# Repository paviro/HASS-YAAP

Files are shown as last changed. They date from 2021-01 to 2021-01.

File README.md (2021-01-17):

# HASS-YAAP
##### Yet another alarm (control) panel for Home Assistant.
* Change alarm system mode (away, home, night, disarmed)
* Welcome people arriving by their name
* Turn off all lights (when you leave for example)

### Usage

##### Arming & Disarming

1. Press `*` to enter code mode
2. Enter Pin
3. Finish sequence by using
   * `A`: Arm Away
   * `B`: Arm Night
   * `C`: Arm Home
   * `D`: Disarm
4. You can also reset the entered code by pressing `*` again

##### Turn of lights

Press `#` while on the main state screen. On any other screen `#` will go back to the main screen.

##### Enable LCD backlight

Press any key.

### Example Screens

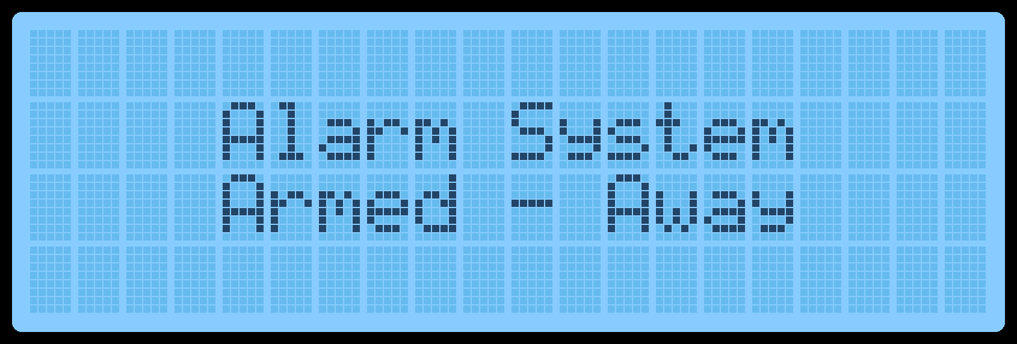
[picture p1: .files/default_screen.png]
Default Screen


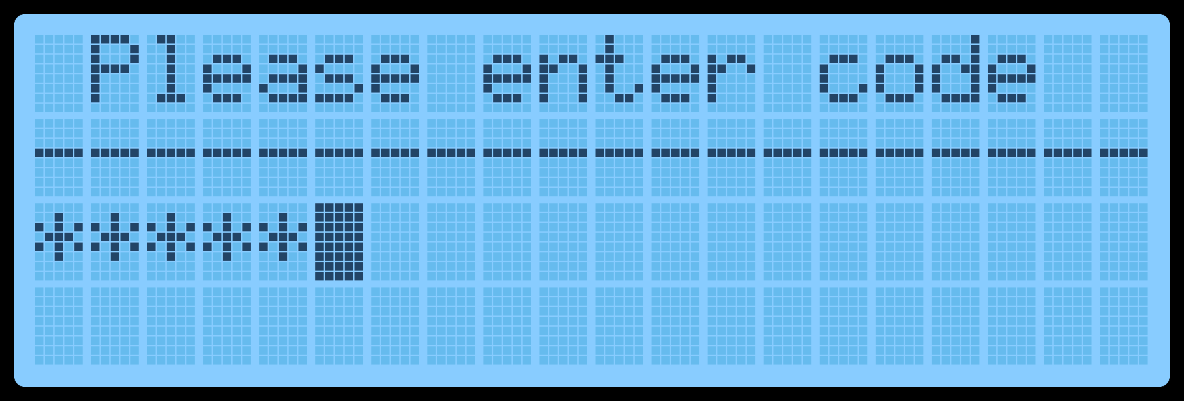
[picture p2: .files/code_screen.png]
Code


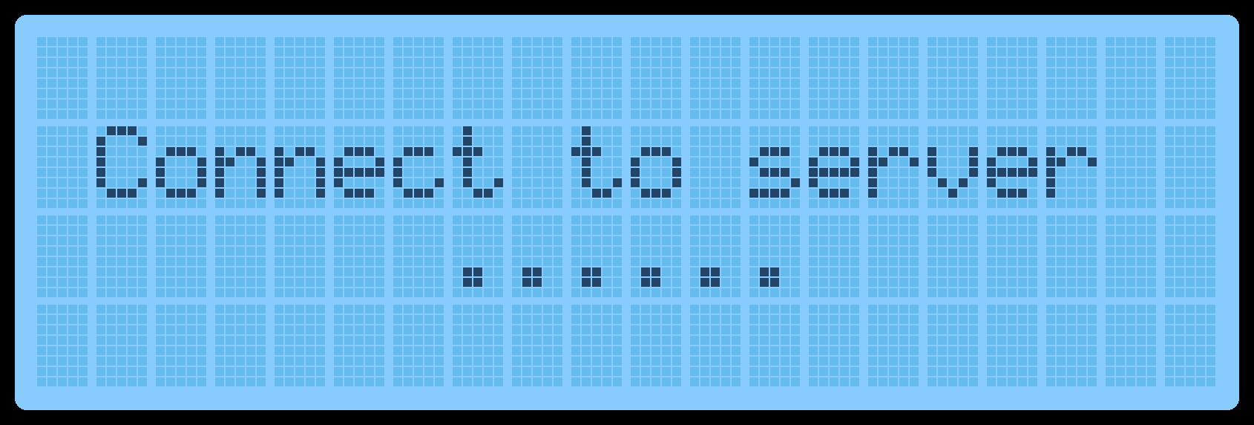
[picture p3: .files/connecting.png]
Connecting


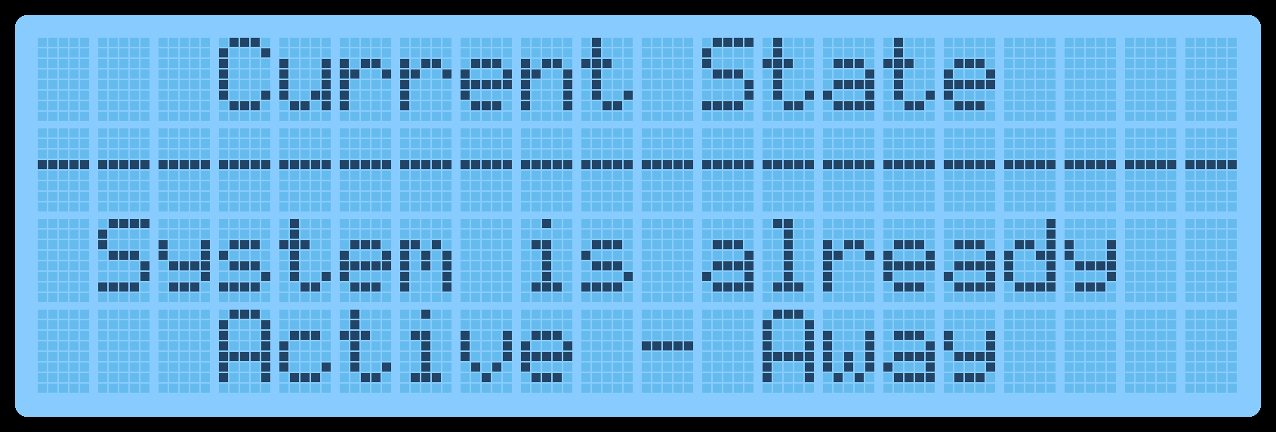
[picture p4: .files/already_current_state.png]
Current State


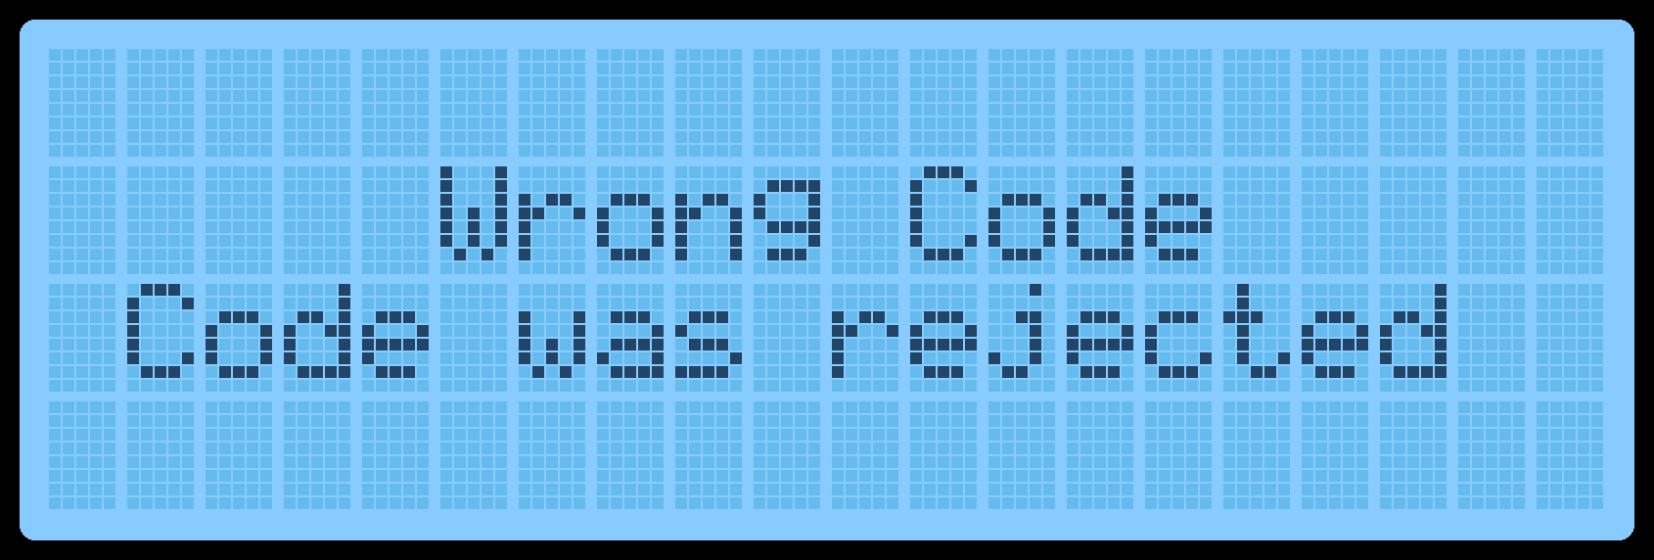
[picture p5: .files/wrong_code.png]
Wrong Code


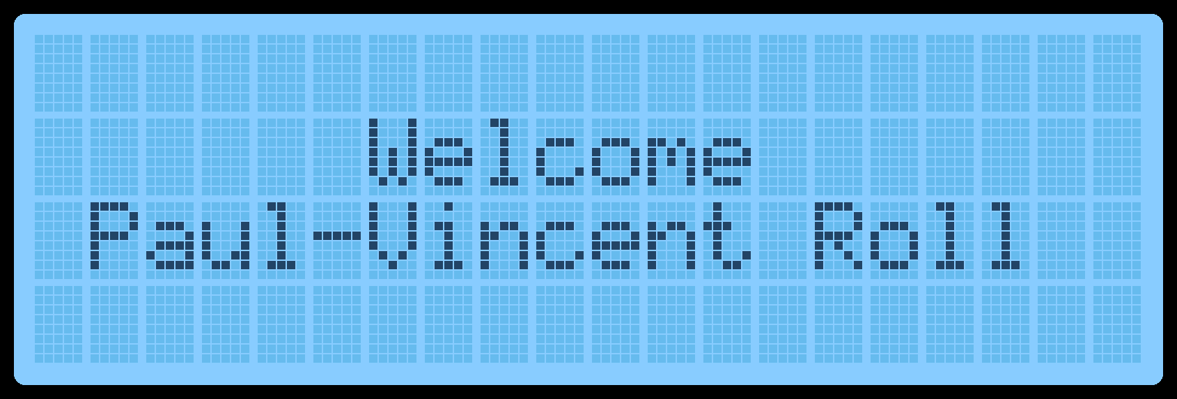
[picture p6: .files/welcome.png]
Welcome


## Used Hardware

#### Parts

* [4x4 Matrix Keypad Keyboard](https://www.az-delivery.de/en/products/4x4-matrix-numpad) 

* [4x20 characters LCD with I2C interface](https://www.az-delivery.de/en/products/hd44780-2004-lcd-display-bundle-4x20-zeichen-mit-i2c-schnittstelle)

* [ESP8266 Board](https://www.az-delivery.de/en/products/nodemcu-lua-amica-v2-modul-mit-esp8266-12e-unverloetet) (You will proably need to change the config in PlatformIO for your board)

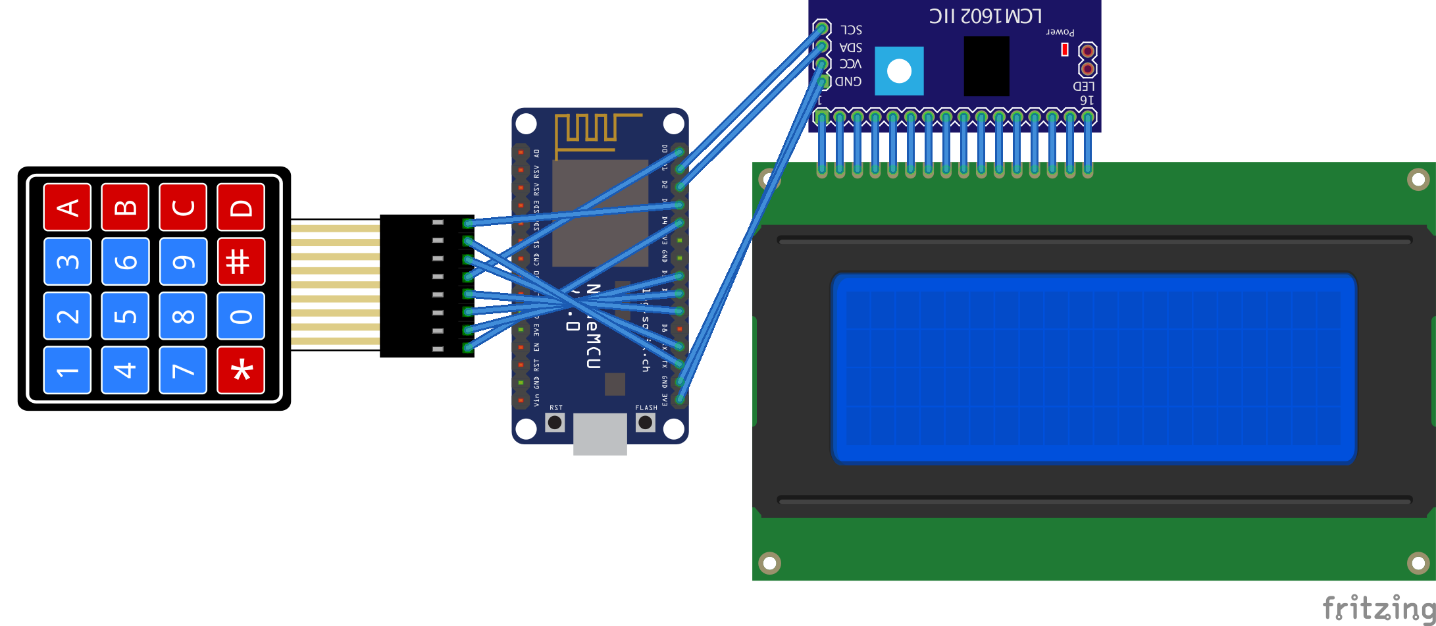
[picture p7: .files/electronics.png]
Electronics
You should probably choose a better pin layout than I did but apparently this is what I used judging from the code 😅

## ESP8266 Configuration

Download and install the [PlatformIO IDE](https://platformio.org).

Create a file called `config.h` in the folder `include` with the contents of [config_example.h](https://github.com/paviro/HASS-YAAP/blob/main/include/config_example.h).

Choose a language file (default selected is English):

```c++
#include "translations/EN.h"
```

Add your WiFi and MQTT credentials:

```c++
#define WiFi_SSID              "WiFi_SSID"
#define WiFi_PW                "WiFi_PW"
#define MQTT_SERVER_IP         "192.168.x.y"
#define MQTT_USER              "MQTT_USER"
#define MQTT_PW                "MQTT_PW"
#define MQTT_CLIENT_NAME       "AlarmControlPanel"
```

**Adjust the other settings to your liking.**

If needed adjust the settings in PlatformIO for your board.

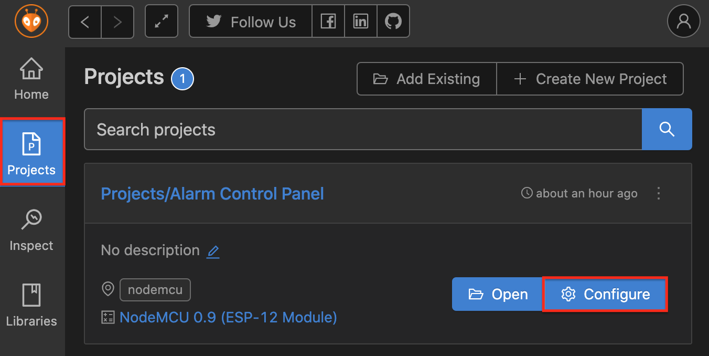
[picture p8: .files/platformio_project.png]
PlatformIO Project


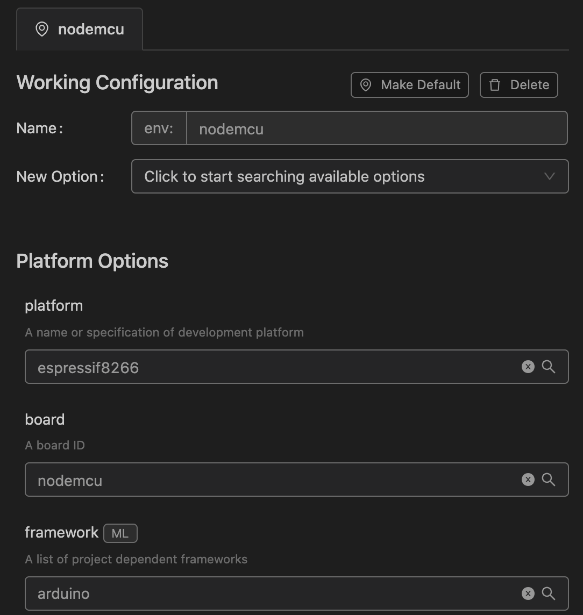
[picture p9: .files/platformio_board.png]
PlatformIO Project


## Home Assistant Configuration

### Requirements

* MQTT Server (for Home Assistant OS: [Mosquitto](https://github.com/home-assistant/addons/tree/master/mosquitto))

* An alarm system (for example: [Manual](https://www.home-assistant.io/integrations/manual/))

* Some Automations (see YAML below)

### MQTT

Setup a MQTT server, configure it in Home Assistant and add an account for the alarm panel on the server.

### Automations

#### Required automations

##### MQTT Alarm Panel - Alarm State

Sends alarm system changes to the panel & receives state requests from the panel.

Replace ```alarm_control_panel.alarmsystem```  with the entity id of your alarm system.

```yaml
- alias: "MQTT Alarm Panel - Alarm State"
  trigger:
    - platform: mqtt
      topic: "alarmpanel/get"
      payload: "state"
    - platform: state
      entity_id: alarm_control_panel.alarmsystem
  action:
    - service: mqtt.publish
      data:
        topic: "alarmpanel/state"
        payload: "{{ states('alarm_control_panel.alarmsystem') }}"
```

##### MQTT Alarm Panel - Alarm State

Automation to change the state of the alarm system. You can define valid codes in the ```variables``` section. 

The name of the code will be used to send a message to a specified phone when the alarm is disabled via the panel. You can disable this by removing the ```notify``` action.

Replace ```alarm_control_panel.alarmsystem```  with the entity id of your alarm system.

Replace ```notify.enter_phone_id_here```  with the entity id of your phone.

```yaml
- alias: "MQTT Alarm Panel - Set Alarm State"
  variables:
    codes:
      23342: "Code 1"
      6563434: "Code 2"
      9189938992: "Code 3"
  trigger:
    - platform: mqtt
      topic: "alarmpanel/arm/away"
    - platform: mqtt
      topic: "alarmpanel/arm/home"
    - platform: mqtt
      topic: "alarmpanel/arm/night"
    - platform: mqtt
      topic: "alarmpanel/disarm"
  action:
    - choose:
        - conditions:
            - condition: template
              value_template: '{{ trigger.payload | int in codes }}'
          sequence:
            - choose:
                - conditions:
                    - condition: template
                      value_template: "{{ trigger.topic == 'alarmpanel/arm/away' }}"
                  sequence:
                    - service: alarm_control_panel.alarm_arm_away
                      entity_id: alarm_control_panel.alarmsystem
                - conditions:
                    - condition: template
                      value_template: "{{ trigger.topic == 'alarmpanel/arm/home' }}"
                  sequence:
                    - service: alarm_control_panel.alarm_arm_home
                      entity_id: alarm_control_panel.alarmsystem
                - conditions:
                    - condition: template
                      value_template: "{{ trigger.topic == 'alarmpanel/arm/night' }}"
                  sequence:
                    - service: alarm_control_panel.alarm_arm_night
                      entity_id: alarm_control_panel.alarmsystem
                - conditions:
                    - condition: template
                      value_template: "{{ trigger.topic == 'alarmpanel/disarm' }}"
                  sequence:
                    - service: alarm_control_panel.alarm_disarm
                      entity_id: alarm_control_panel.alarmsystem
                    - service: notify.enter_phone_id_here
                      data_template:
                        message: >
                          Alarm system disarmed with code: {{codes[trigger.payload  | int]}}
                        title: "⚠️ Warning Alarmpanel"
      default:
        - service: mqtt.publish
          data:
            topic: "alarmpanel/arm/error"
            payload: "invalidCode"
        - service: notify.enter_phone_id_here
          data_template:
            message: >
               A wrong code was entered into the alarm panel: {{trigger.payload}}
            title: "⚠️ Warning Alarmpanel"
```

##### MQTT Alarm Panel - Lights off

Turns of your lights when ```#``` is pressed on the panel while on the alarm state screen.

```yaml
- alias: "MQTT Alarm Panel - Lights off"
  trigger:
    - platform: mqtt
      topic: "alarmpanel/lights"
      payload: "off"
  action:
    - service: light.turn_off
      entity_id: all
    - service: mqtt.publish
      data:
        topic: "alarmpanel/lights/callback"
        payload: "success"
```

#### Optional automations

##### Welcome Notification

The automation below will send the name of people arriving at your home to the alarm panel to display. 

If you have a motion / door sensor in the area it will wait for someone to be present near the panel. Remove the first action if you don't have one.

```yaml
- alias: "Welcome Notification"
  trigger:
    platform: event
    event_type: state_changed
  mode: parallel
  condition:
    condition: and
    conditions:
      - condition: template
        value_template: "{{ trigger.event.data.new_state is defined }}"
      - condition: template
        value_template: "{{ trigger.event.data.old_state is defined }}"
      - condition: template
        value_template: "{{ trigger.event.data.new_state.domain == 'person' }}"
      - condition: template
        value_template: "{{ trigger.event.data.new_state.state == 'home' }}"
      - condition: template
        value_template: "{{ trigger.event.data.old_state.state != 'home' }}"
  action:
    - wait_template: "{{ is_state('binary_sensor.motion_sensor_near_panel', 'on') }}"
      timeout: 300
      continue_on_timeout: false
    - service: mqtt.publish
      data:
        topic: "person/arrived"
        payload: "{{state_attr(trigger.event.data.entity_id, 'friendly_name')}}"
```

##### Motion Sensor

Turn on the LCD backlight if a motion sensor near the panel is triggered.

```yaml
- alias: "MQTT Alarm Panel - Turn LCD on when motion is detected"
  trigger:
    platform: state
    entity_id: binary_sensor.motion_sensor_near_panel
    to: 'on'
  action:
    - service: mqtt.publish
      data:
        topic: "alarmpanel/lcd"
        payload: "on"
```

## Roadmap

* TLS Support (Anyone want to give it a shot?)
* Support more display types?
* More translations

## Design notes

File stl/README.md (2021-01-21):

# Case files

In this folder you can find the STL files for the case. They were designed by Clemens Szelies.

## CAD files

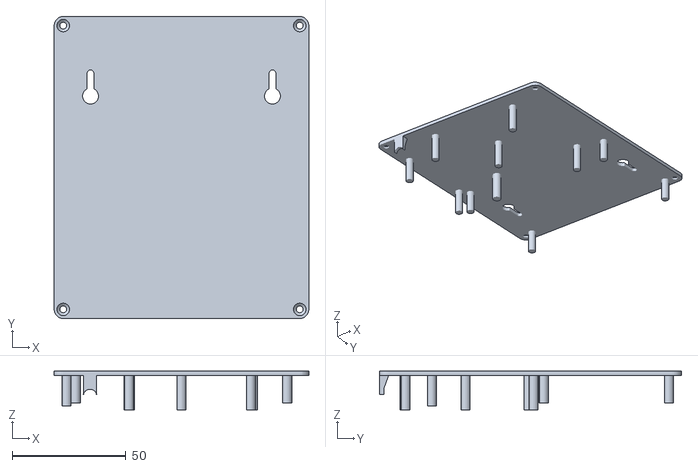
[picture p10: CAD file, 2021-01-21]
stl/Alarm-Panel Back x1.stl
112.0 x 132.8 x 17.1

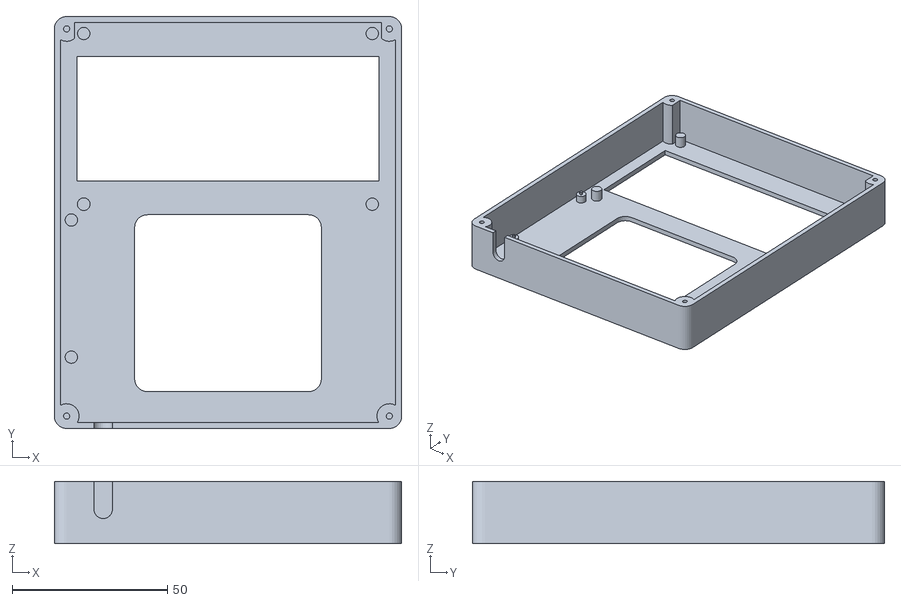
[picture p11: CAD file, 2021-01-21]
stl/Alarm-Panel Front x1.stl
112.0 x 132.8 x 20.1

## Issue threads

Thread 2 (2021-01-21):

Case files

lubbertkramer, 2021-01-21:
Did you print the case yourself or did you also buy this? If you have printed it where can i find the files ?

Thanks!

paviro, 2021-01-21:
The case was designed by a friend of mine. He is still finishing up some things as soon as he is done I’ll add it to the repo.

lubbertkramer, 2021-01-21:
Great to hear! But is it possible to also share the case you have used/printed?

paviro, 2021-01-21:
Mhh? As I said it’s still being finished up. I had to improvise some things on the particular one I printed.

paviro, 2021-01-21:
Files added at https://github.com/paviro/HASS-YAAP/tree/main/stl

Closed 2021-01-21.

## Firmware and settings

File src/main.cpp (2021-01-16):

#include <Arduino.h>
#include <EspMQTTClient.h>
#include <Dictionary.h>
#include <Keypad.h>
#include <Wire.h>
#include <LiquidCrystal_I2C.h>
#include <screen.h>
#include <config.h>

// general
String currentAlarmState;
String code;

// Dictionaries
Dictionary & internalStates = * (new Dictionary(6));
Dictionary & strings = * (new Dictionary(6));

EspMQTTClient client(WiFi_SSID,WiFi_PW,MQTT_SERVER_IP,MQTT_USER,MQTT_PW,MQTT_CLIENT_NAME);

byte keypadRowPins[KEYPAD_ROWS] = {KEYPAD_ROW_PINS};
byte keypadColPins[KEYPAD_COLS] = {KEYPAD_COL_PINS};
Keypad customKeypad = Keypad(makeKeymap(keypadMap), keypadRowPins, keypadColPins, KEYPAD_ROWS, KEYPAD_COLS);

LiquidCrystal_I2C lcd(SCREEN_ADDRESS, SCREEN_WIDTH, SCREEN_HEIGHT);

Screen screen(DEFAULT_TIMEOUT*1000, BACKLIGHT_TIMEOUT*1000, WELCOME_MESSAGE_TIMEOUT*1000, TEXT_SCROLL_SPEED_DELAY);

void setup() {
  lcd.init();
  strings.jload(languageJSON);

  // Needed for comparision between new requested state and current state
  internalStates("away", "armed_away");
  internalStates("home", "armed_home");
  internalStates("night", "armed_night");
  internalStates("disarm", "disarmed");
}

void Screen::turnOnLCD() {
  backlightMillis = millis();
  lcd.backlight();
}

void Screen::drawCenterText(int row, String text) {
  int offset = (SCREEN_WIDTH - text.length()) / 2;
  lcd.setCursor(offset, row);
  lcd.print(text);
}

String Screen::repeatStringByDisplayWidth(String stringToRepeat) {
  String string;
  for (int i = 0; i < SCREEN_WIDTH; i++) {
    string += stringToRepeat;
  }
  return string;
}

void Screen::scrollText() {
  if (scrollingStarted == true and millis() - lastScrolled >= (unsigned)scrollDelay) {
    String scrollPadding = repeatStringByDisplayWidth(" ");
    String text = scrollPadding + peopleArrived + scrollPadding;
    String displaySubstring = text.substring(scrollStringStart, scrollStringStart + SCREEN_WIDTH);

    lcd.setCursor(0, 2);
    lcd.print(displaySubstring);

    scrollStringStart += 1;
    lastScrolled = millis();
    if (scrollStringStart > ((signed)text.length() - SCREEN_WIDTH)) {
      scrollStringStart = 0;
    }

  } else if (screen.displayed != "peopleArrived") {
    scrollingStarted = false;
  }
}

void Screen::drawConnecting() {
  const char *loadingAnimation[11] = { ".", "..", "...", "....", ".....", "......", ".......", "........", ".........", "..........", "          " };
  if (screen.displayed != "connectingToServer") {
    screen.displayed = "connectingToServer";
    animationStep = 0;
    lcd.clear();
    drawCenterText(1, strings["connecting"]);
    turnOnLCD();
  } else if (millis() - lastAnimated >= 100) {
    lastAnimated = millis();
    drawCenterText(2, loadingAnimation[animationStep]);
    if (animationStep == 10) {
      animationStep = 0;
    } else {
      animationStep += 1;
    }
  }
}

void Screen::drawAlarmSystemState() {
  screen.displayed = "alarmSystemState";
  lcd.clear();
  drawCenterText(1, strings["systemTitle"]);
  drawCenterText(2, strings[currentAlarmState]);
  turnOnLCD();
}

void Screen::drawArmingError(int error) {
  screen.displayed = "armingError";
  autoTimeoutMillis = millis();
  lcd.clear();
  switch (error) {
    case (0):
      drawCenterText(1, strings["invalidCodeHeader"]);
      drawCenterText(2, strings["invalidCodeMessage"]);
      break;
    case (1):
      drawCenterText(0, strings["currentStateHeader"]);
      drawCenterText(1, repeatStringByDisplayWidth("-"));
      drawCenterText(2, strings["currentStateMessage"]);
      drawCenterText(3, strings[currentAlarmState]);
      break;
  }
}

void Screen::drawLightsOff(int state) {
  screen.displayed = "lightsTurnedOff";
  autoTimeoutMillis = millis();
  lcd.clear();
  drawCenterText(1, strings["lightsTurnOffHeader"]);
  switch (state) {
    case (0):
      drawCenterText(2, strings["lightsTurnOffRequested"]);
      break;
    case (1):
      drawCenterText(2, strings["lightsTurnOffSuccess"]);
      break;
  }
  turnOnLCD();
}

void Screen::drawPersonArrived(const String & person) {
  personArrivedMillis = millis();

  if (screen.displayed != "peopleArrived") {
    peopleArrived = "";
    lcd.clear();
    drawCenterText(1, strings["peopleArrivedWelcome"]);
    turnOnLCD();
    screen.displayed = "peopleArrived";
  }

  if (peopleArrived.length() == 0) {
    peopleArrived = person;
  } else {
    peopleArrived += " & " + person;
  }

  if (peopleArrived.length() > SCREEN_WIDTH) {
    if (scrollingStarted == false) {
      scrollingStarted = true;
      scrollStringStart = 0;
    }
  } else {
    drawCenterText(2, peopleArrived);
  }
}

void Screen::drawCodeInputMode(const char & input) {
  screen.displayed = "codeInput";
  autoTimeoutMillis = millis();
  if (input == '*') {
    lcd.clear();
    drawCenterText(0, strings["enterCode"]);
    drawCenterText(1, repeatStringByDisplayWidth("-"));
    cursorPosRow = 0;
    cursorPosCol = 2;
    lcd.setCursor(cursorPosRow, cursorPosCol);
    code = "";
  } else {

    if (code.length() < SCREEN_WIDTH * 2 - 1) {
      lcd.setCursor(cursorPosRow, cursorPosCol);
      if (SHOW_PIN == true) {
        lcd.print(input);
      } else {
        lcd.print("*");
      }
      cursorPosRow += 1;
      code += input;
    }

    if (code.length() == SCREEN_WIDTH) {
      cursorPosRow = 0;
      cursorPosCol = 3;
      lcd.setCursor(cursorPosRow, cursorPosCol);
    }
  }
  turnOnLCD();
}

void Screen::checkTimeout() {
  unsigned long currentMillis = millis();

  // Screen
  if (currentMillis - backlightMillis >= (unsigned)backlightTimeout and screen.displayed == "alarmSystemState") {
    lcd.noBacklight();
  }

  // autoTimeout
  if (screen.displayed == "codeInput" or screen.displayed == "lightsTurnedOff" or screen.displayed == "armingError") {
    if (currentMillis - screen.autoTimeoutMillis >= (unsigned)autoTimeout) {
      if (screen.displayed == "codeInput") {
        code = "";
      }
      screen.drawAlarmSystemState();
    }
  }

  // person arrived timeout
  if (screen.displayed == "peopleArrived") {
    if (currentMillis - screen.personArrivedMillis >= (unsigned)peopleArrivedScreenTimeout) {
      screen.drawAlarmSystemState();
    }
  }
}

void armSystem(const String & type, const String & pin) {
  if (currentAlarmState == internalStates[type]) {
    screen.drawArmingError(1);
  } else {
    if (type == "disarm") {
      client.publish("alarmpanel/disarm", pin);
    } else {
      client.publish("alarmpanel/arm/" + type, pin);
    }
  }
  code = "";
}

void turnLightsOff() {
  client.publish("alarmpanel/lights", "off");
  screen.drawLightsOff(0);
}


void parseInput(const char & input) {
  if (input == 'A' and screen.displayed == "codeInput") {
    armSystem("away", code);
  } else if (input == 'B' and screen.displayed == "codeInput") {
    armSystem("night", code);
  } else if (input == 'C' and screen.displayed == "codeInput") {
    armSystem("home", code);
  } else if (input == 'D' and screen.displayed == "codeInput") {
    armSystem("disarm", code);
  } else if (input == '#' and screen.displayed == "alarmSystemState") {
    turnLightsOff();
  } else if (input == '#' and screen.displayed != "alarmSystemState") {
    screen.drawAlarmSystemState();
  } else if (input == '*' or screen.displayed == "codeInput") {
    screen.drawCodeInputMode(input);
  } else {
    screen.turnOnLCD();
  }
}

void readKeypad() {
  char inputKey = customKeypad.getKey();
  if (inputKey) {
    parseInput(inputKey);
  }
}

void onLCD(const String & message) {
  if (message == "on") {
    screen.turnOnLCD();
  } else if (message == "off") {
    lcd.noBacklight();
  }
}

void onArmingError(const String & message) {
  if (message == "invalidCode") {
    screen.drawArmingError(0);
  }
}

void onPersonArrived(const String & message) {
  screen.drawPersonArrived(message);
}

void onLightsCallback(const String & message) {
  if (message == "success") {
    screen.drawLightsOff(1);
  }
}

void onAlarmSystemStateChange(const String & message) {
  currentAlarmState = message;
  if ( !(screen.displayed == "codeInput" and (currentAlarmState == "triggered" or currentAlarmState == "pending")) )
  {
    screen.drawAlarmSystemState();
  }
}

void onConnectionEstablished() {
  client.subscribe("person/arrived", onPersonArrived);
  client.subscribe("alarmpanel/state", onAlarmSystemStateChange);
  client.subscribe("alarmpanel/arm/error", onArmingError);
  client.subscribe("alarmpanel/lights/callback", onLightsCallback);
  client.subscribe("alarmpanel/lcd", onLCD);

  client.publish("alarmpanel/get", "state");
}

void loop() {
  client.loop();

  if (client.isConnected() == true) {
    readKeypad();
    screen.checkTimeout();
    screen.scrollText();
  } else {
    screen.drawConnecting();
  }

  if (screen.displayed == "codeInput") {
    lcd.blink();
  } else {
    lcd.noBlink();
  }

}

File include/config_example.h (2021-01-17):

// !!! ------------------------------------ !!!
// COPY THIS FILE TO A NEW FILE NAMED: config.h
// !!! ------------------------------------ !!!


// ------------------------------------ 
// Language
// Available: EN.h, DE.h, NL.h
// ------------------------------------ 

// Use one of the available files or create a new one
#include "translations/EN.h"



// ------------------------------------ 
// WLAN & MQTT Configuration
// ------------------------------------ 

#define WiFi_SSID              "WiFi_SSID"
#define WiFi_PW                "WiFi_PW"
#define MQTT_SERVER_IP         "192.168.x.y"
#define MQTT_USER              "MQTT_USER"
#define MQTT_PW                "MQTT_PW"
#define MQTT_CLIENT_NAME       "AlarmControlPanel"



// ------------------------------------ 
// Timeouts
// ------------------------------------ 

// Timeout for switching back to the main state screen
#define DEFAULT_TIMEOUT         15
// Backlight timeout when on main state screen
#define BACKLIGHT_TIMEOUT       10
// How long to display the names of people coming home
#define WELCOME_MESSAGE_TIMEOUT 60

// Delay before scrolling to the next position in ms (used when the names for the welcome screen are too long)
#define TEXT_SCROLL_SPEED_DELAY 350



// ------------------------------------ 
// LCD Configuration
// ------------------------------------ 

// I2C address of LCD screen
#define SCREEN_ADDRESS          0x27

// LCD size - using a different size will cause UI errors for now
#define SCREEN_WIDTH            20
#define SCREEN_HEIGHT           4

// true = show entered pin - false = replace with *
#define SHOW_PIN                true



// ------------------------------------ 
// Keypad Configuration
// ------------------------------------

// Number of rows and cols on the keypad
#define KEYPAD_ROWS             4
#define KEYPAD_COLS             4

// GPIO Pins of keypad rows and cols
#define KEYPAD_ROW_PINS         D4, D5, D6, D7
#define KEYPAD_COL_PINS         D0, D9, D10, D3

// Keypad layout (Keypad with letters needed for using this code!)
char keypadMap[KEYPAD_ROWS][KEYPAD_COLS] = {
  {'1', '2', '3', 'A'},
  {'4', '5', '6', 'B'},
  {'7', '8', '9', 'C'},
  {'*', '0', '#', 'D'}
};

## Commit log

2021-01-16 Stay on codeInput screen when alarm is triggered or is pending
    Stays on the codeInput screen in case the alarm gets triggered or is pending after the mode is entered so one can finish entering the pin.
2021-01-21 Added case files
    [Alarm-Panel Back x1.stl, Alarm-Panel Front x1.stl]
